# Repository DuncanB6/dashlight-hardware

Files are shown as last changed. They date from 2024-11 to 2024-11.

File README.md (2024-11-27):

# Hardware for Dashlight Project

This repository includes files used in the design and build of hardware for the Dashlight project. Find information about the software side of the project at https://github.com/DuncanB6/dashlight-firmware.

Although most files and build information is available, trying to reproduce this project without modification is not advised. Differences in your car (either hardware or software) could easily cause headaches. This was built for a 2002 Mazda Protege5.

## Overview

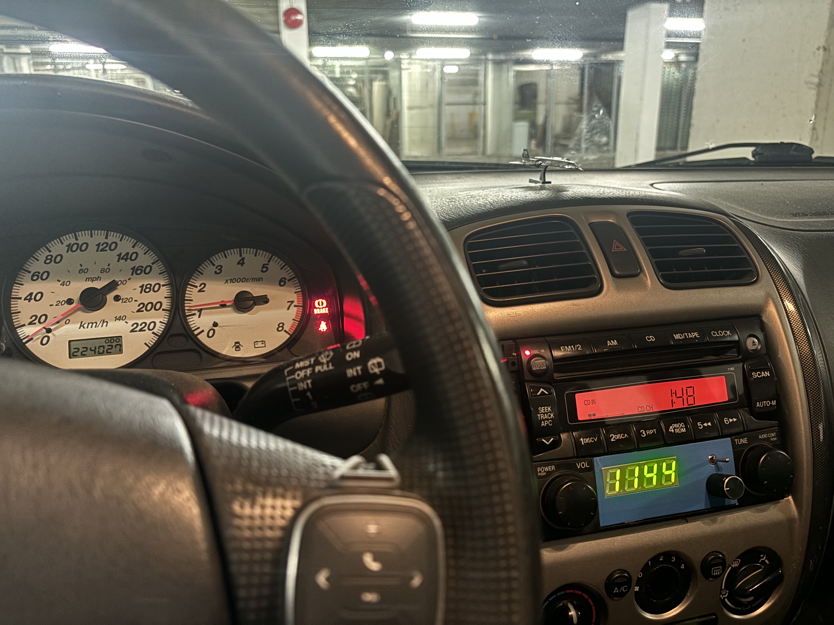
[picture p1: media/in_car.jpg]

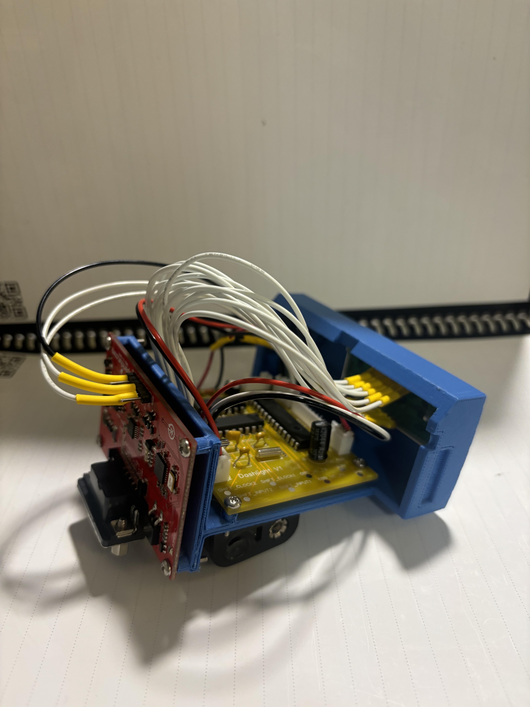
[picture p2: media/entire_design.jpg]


The objective of this project is to provide a display for my car (The Yellow Peril) that displays some data while driving. 

The core to this project is a main PCB which houses a PIC32 microcontroller and the hardware necessary for interface with a 7 segment LED as well as several peripherals. Also includes a RTCC for timekeeping. It's a simple 2 layer PCB equiped with test points, PH connectors, and supporting components for the microcontroller. All components are through hole for easy assemble and to enable breadboard debugging.

This PCB has two versions. Version 1 was unusable because of incorrect component sizes. Version 2 is currently in use.

The PCB and all components are mounted to a 3D printed rack, which is inserted into the empty CD changer slot in my car.

## Prototyping

Schematic

To develop this device, a prototype was constructed using a breadboard. The components are nearly identical to the finished PCB design. See the BoM for information on parts.

## Main Board

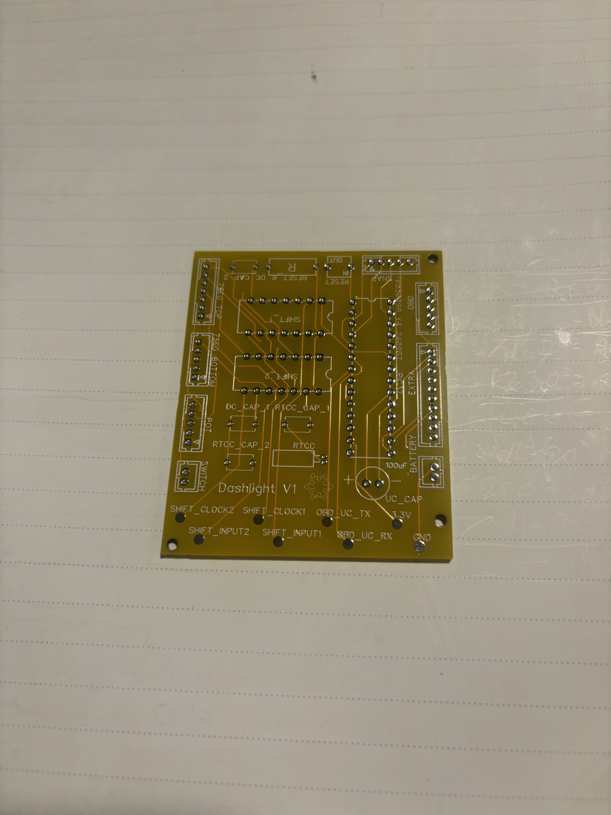
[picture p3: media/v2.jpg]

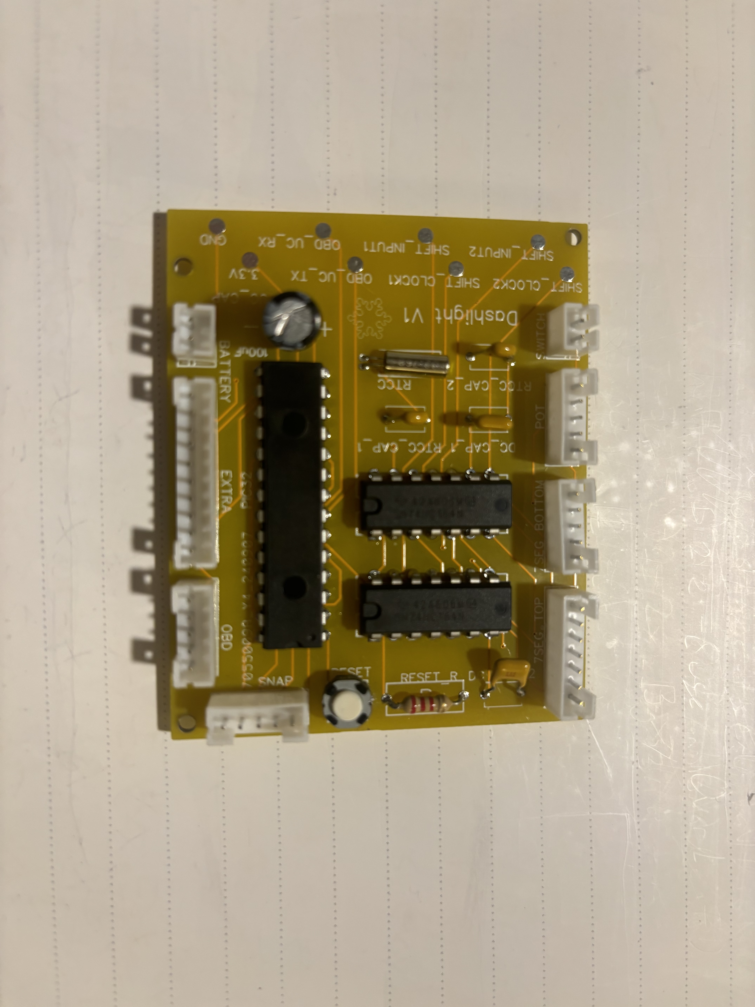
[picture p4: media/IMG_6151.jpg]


This design uses a PIC32 MX130F064B-I/SP microcontroller. It uses a 32.768kHz oscillator for its RTCC (Real Time Clock and Calendar). It uses two SN74HC164N shift registers to control the 7 segment display. PH connectors are used to connect the main PCB to some of the peripherals. A reset button is present to reset the PIC32.

Test points are available for the UART communication with the OBD2 to UART peripheral, the inputs to the shift registers, and the power supply.

## Peripherals

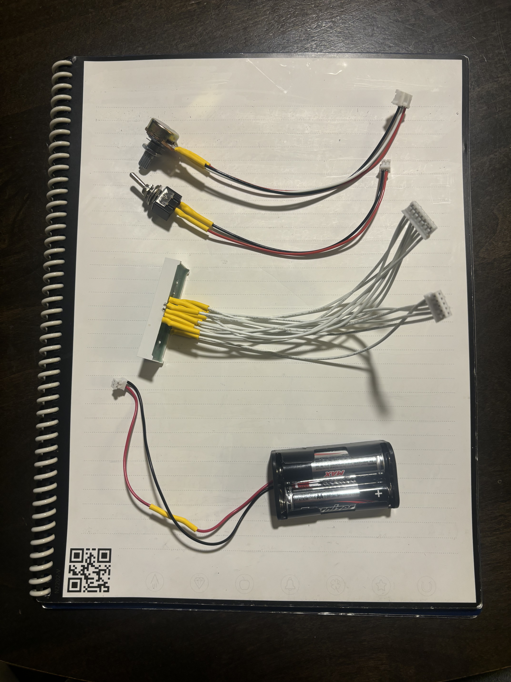
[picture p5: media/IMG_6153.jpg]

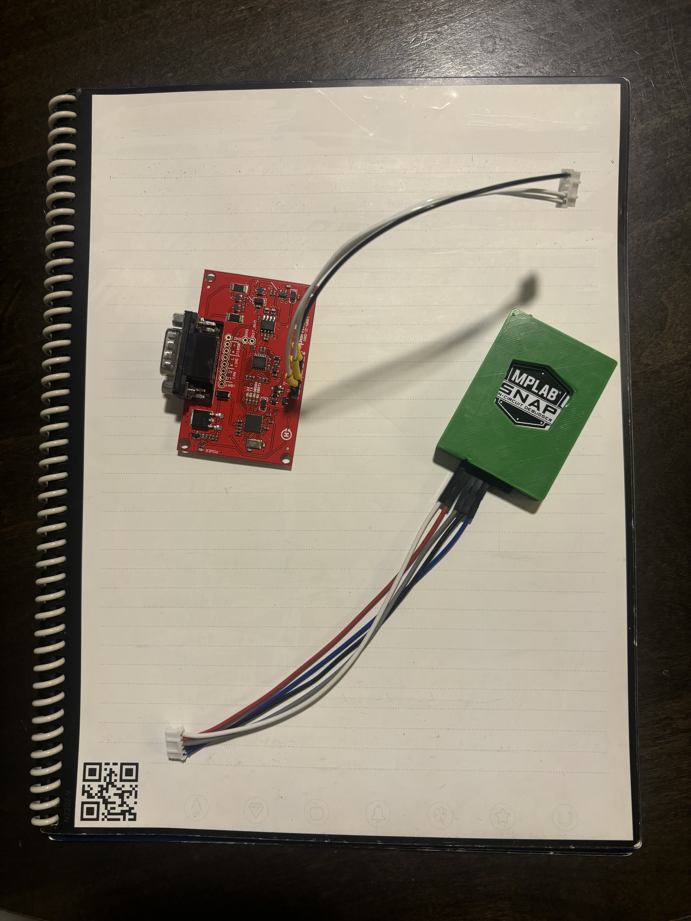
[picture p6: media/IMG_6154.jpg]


Peripherals connect to the main board using one or more PH style connectors. This is to allow for greater modularity. Peripherals include:
- 7 segment display: Displays all data
- Switch: On-off switch
- Potentiometer: Allows user to switch between software modes
- Battery: Power supply
- OBD2 to UART board: Translates data from the OBD2 port to UART
- MPLAB Snap: For debugging and flashing

Additionally, some unused pins are available on a 10 pin PH connector for use with future peripherals.

## Design Files

EasyEDA was used for design. The schematic files are available in this repository, as well as the most recent Gerber file for fabrication. See BoM for components used with this PCB, some parts may differ slightly from PCB design.

## Rack

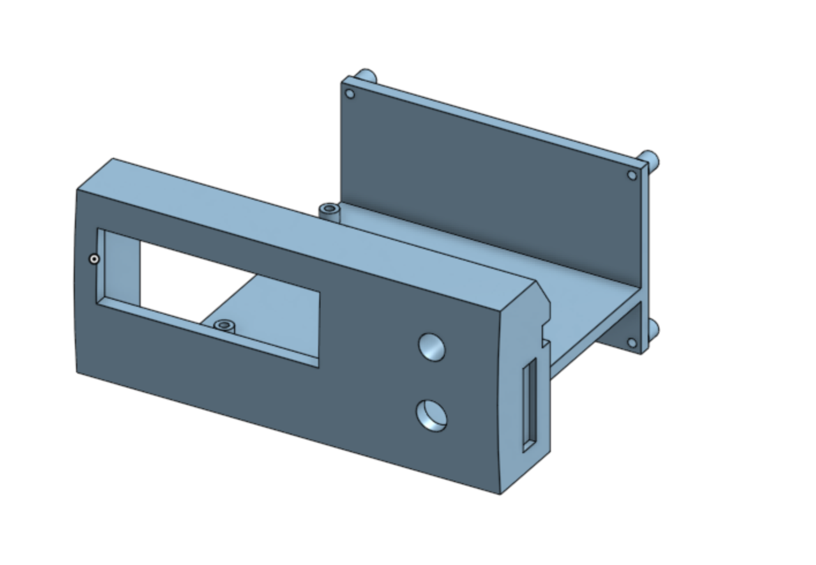
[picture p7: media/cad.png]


The rack is printed in PLA using a Prusa MKS+. It went through a series of iterations that aimed to fit the hardware in a limited space and fit parts accurately. It's not an ideal solution, as some modifications had to be made for installation. STL and STEP files are available here.

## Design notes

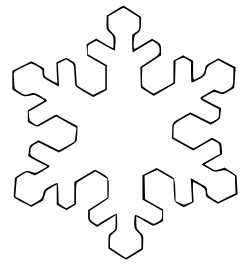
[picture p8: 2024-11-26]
media/snowflake.png

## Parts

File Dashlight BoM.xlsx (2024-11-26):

Item | Description | Total Price | Supplier | Quantity | Link
Breadboard (x2) | Breadboards for prototyping | 21.4 | Digikey | 2 | https://www.digikey.ca/en/products/detail/twin-industries/TW-E40-1020/643111
MPLAB Snap | For debugging and flashing PIC32 uCs | 58.58 | Digikey | 1 | https://www.digikey.ca/en/products/detail/microchip-technology/PG164100/9562532
Toggle switch | On-off switch | 2 | RP Electronics | 1 | NA
Battery holder | Power supply | 5 | RP Electronics | 1 | NA
Shift registers | Needed to use the 7-segment LED, used during prototyping | 4 | RP Electronics | 3 | NA
32.768kHz oscillator | Needed to use the RTCC | 3.2 | Sparkfun | 2 | https://www.sparkfun.com/products/540
12pF capacitors | Needed for the oscillator for the RTCC | 1.2 | Sparkfun | 4 | https://www.sparkfun.com/products/8571
OBD to DB9 cable | Links car to Sparkfun OBD | 10.95 | Sparkfun | 1 | https://www.sparkfun.com/products/10087
Sparkfun OBD2 to UART | Communicate easily between car and uC | 56.95 | Sparkfun | 1 | https://www.sparkfun.com/products/9555
Shipping | Sparkfun order | 28.75 | Sparkfun | NA | NA
PCB V1 | Main PCB | 4.98 | PCBWay | 5 | NA
PCB V2 | Main PCB | 4.88 | PCBWay | 5 | NA
Shift registers | SN74HC164N, for 7 segment display | 2 | Digikey | 2 | https://d.digikey.com/dc/mn-w0iJh4uEE_bUitNCuXsaMqkw5UctQEQXQivOAnBO6lV7ZAfP09QGvP-fW20PQWT0wM4Ey2VW379AcBdv2pXCyD2dMkH8PCHr8xWxV9WGlbps_WzeZ1lZHhA77_NdMikjnq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
7 segment display | To display data | 5.34 | Digikey | 1 | https://d.digikey.com/dc/mn-w0iJh4uEE_bUitNCuXsaMqkw5UctQEQXQivOAnBOsEePTphTcEfEIf4pBy1yTgiYfdI-jReduRjfehss0Hm6ri2QEbKcrR-AArau7jtbGAUt1ZHHsP2iteR6m6q5ETLTSR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
Potentiometer | To toggle between modes | 2.06 | Digikey | 1 | https://d.digikey.com/dc/mn-w0iJh4uEE_bUitNCuXsaMqkw5UctQEQXQivOAnBO4OE6Avoi6ufNDnP-V4qjlDEt3URJHq6_Nyn98oaUerk8wLXtBotnK16YM4T7SFQ2mtnH-hHAxMvqgXqgBjpwA_galD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
Various wiring | For wiring peripherals to the board | 19.32 | Digikey | NA | https://d.digikey.com/dc/mn-w0iJh4uEE_bUitNCuXsaMqkw5UctQEQXQivOAnBMZvDLCKnQmVcZjfb-IKDRi3GXWCTnXid2uknUhnXG6IEDQD_kF-KJ93BbLT2cHXpdi0NP86E-IXvSwPFjwbFD_FphG0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
Heatshrink | For making connections on peripheral wiring | 5.71 | Digikey | NA | https://d.digikey.com/dc/mn-w0iJh4uEE_bUitNCuXsaMqkw5UctQEQXQivOAnBMXK6ptcF7hKc5KxfjSpy1xAfgom8-P2RoMewiUIqKPzuroVMGRDQQC5CODvkCPyo6Z16CerGkzjjfGyLyGAKjUkbHBh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
Crimper | For creating connections for peripheral wiring | 20.69 | Digikey | 1 | https://d.digikey.com/dc/mn-w0iJh4uEE_bUitNCuXsaMqkw5UctQEQXQivOAnBP3NELo1Ga1Anc4cBJgZizYw2Hb4-l34iFFXKt_ysb8biWKulxlOkmPo2GhJhalz8n1NUzs9NQ9NlEoJZy-wZaGqEYjp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
Various connectors | Connectors for peripherals | 8.02 | Digikey | NA | https://www.digikey.ca/en/products/detail/jst-sales-america-inc/B7B-PH-K-S/926616
Crimps | Making connectors for peripherals | 3.04 | Digikey | NA | https://www.digikey.ca/en/products/detail/jst-sales-america-inc/SPH-001T-P0-5L/1300245
Screws | Connecting components to 3D printed rack | 15.84 | Digikey | 16 | https://www.digikey.ca/en/products/detail/apm-hexseal/RM2X12MM-2701/3712290
Heat gun | For making connections with shrink wrap | 23.25 | Digikey | 1 | https://www.digikey.ca/en/products/detail/sparkfun-electronics/TOL-10326/7229872
TOTAL: | 307.16
TOTAL EXCLUDING TOOLS: | 175.89

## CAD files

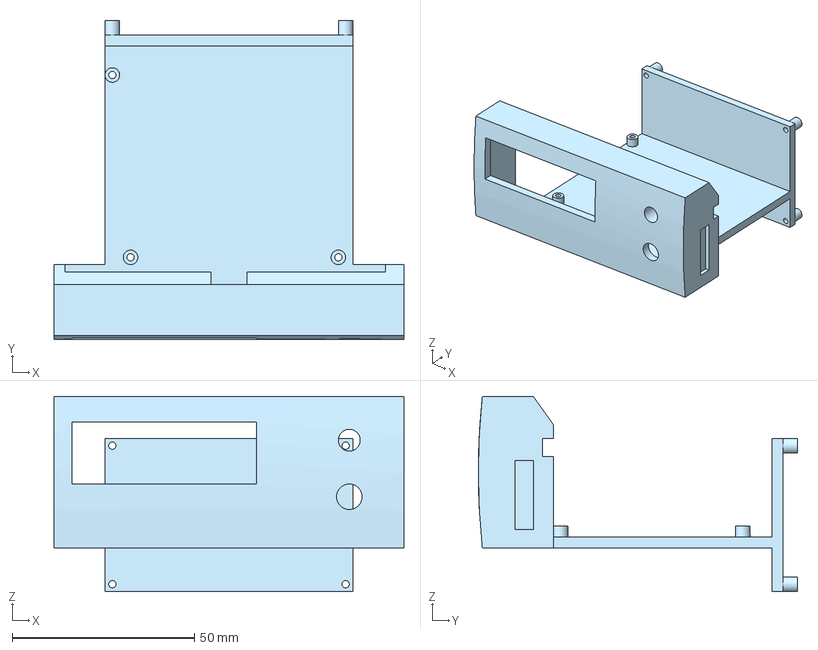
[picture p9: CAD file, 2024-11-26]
rack/Dashlight.step
96.0 x 87.6 x 53.5 mm

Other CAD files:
rack/Dashlight.stl

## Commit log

2024-11-26 added hardware files, updated readme
    [Dashlight BoM.xlsx, Dashlight.step, Dashlight.stl]
2024-11-26 moved cad files to rack
    [Dashlight.step, Dashlight.stl]
